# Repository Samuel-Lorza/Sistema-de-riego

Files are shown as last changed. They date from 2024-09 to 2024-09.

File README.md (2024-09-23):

# Sistema-de-riego automatico
Sistema de riego automatico con el uso del ESP32

## Integrantes:

Samuel Lorza-Miguel Pardo-Juan Crespo- Diego García

## Descripción

El presente proyecto, es un sistema de riego automático realizado con un microprocesador de referencia ESP32, la utilidad del sistema radica en la asistencia al usuario para regar plantas en momentos de ausencia, tales como un viaje, una reunión, o que el dueño este ocupado y no pueda cuidar de sus plantas. Con base en lo anterior, el sistema es totalmente programable en cuanto a la temperatura y la humedad que el usuario necesite, dependiendo de las necesidades de la planta. Se ha de mencionar que el usuario debe proveer de agua al sistema, por ejemplo, poniendo un tanque plástico con agua, además, el sistema hará un ruido con el objetivo de recordar al usuario de llenar el tanque (fuente de agua) cuando este tiene un bajo nivel de agua.

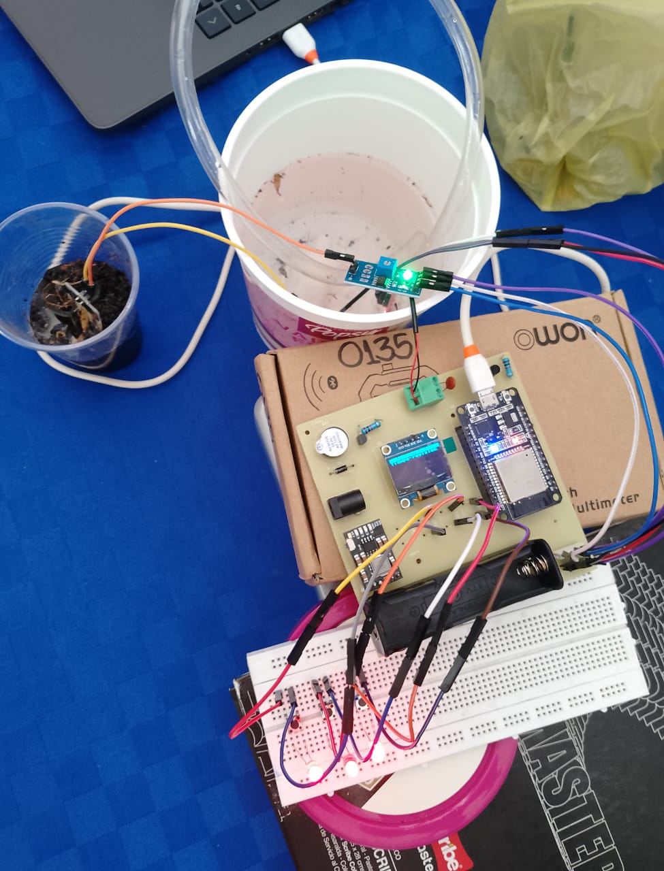
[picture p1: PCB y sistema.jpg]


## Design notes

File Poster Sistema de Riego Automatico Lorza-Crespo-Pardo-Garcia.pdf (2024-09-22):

## Introducción

## Objetivos

El objetivo principal del proyecto es brindar una herramienta sencilla, fácil de implementar y accesible la cual facilite el cuidado de las plantas en el hogar, teniendo en cuenta que no tenga el tiempo necesario para el cuidado de su planta, pero aun así desee tener una en casa pues, aparte de brindar un toque estético, las plantas colaboran en la calidad del aire y esto es aún más significante en las ciudades grandes como Bogotá.

## Impactos

## Placa de Circuito Impreso

## Diagrama de Flujo

# Sistema De Riego Automático

Taller De Ingeniería Electrónica
Johnny German Cubides Castro

Juan Pablo Crespo Gutiérrez jcrespog@unal.edu.co

Miguel Ángel Pardo Castro
mpardoc@unal.edu.co

Samuel Martin Lorza Monroy slorza@unal.edu.co

Diego Garcia Romero
diegarciaro@unal.edu.co
- Reducción de la
huella de carbono.

Nuestro proyecto es un Sistema de Riego Automático realizado con un microprocesador de referencia ESP32 y sensores como, el sensor de nivel del agua y el sensor de humedad y temperatura. La utilidad del sistema radica en la asistencia al usuario para regar plantas en momentos de ausencia y no pueda cuidar de estas. El sistema es totalmente programable en cuanto a la temperatura y la humedad dependiendo de las necesidades de la planta. Se ha de mencionar que el usuario debe proveer de agua al sistema, además, el sistema hará un ruido con el objetivo de recordar al usuario de llenar el tanque (fuente de agua) cuando este tenga un bajo nivel de agua.

- Prevención de un uso
excesivo del agua.
- Uso constante de
energía eléctrica.
- Aumento en el uso y
desechos electrónicos.
- Costos de producción
y mantenimiento.
- Dependencia en la
tecnología.
- Mayor eficiencia en el
manejo del tiempo.
- Accesibilidad y mejora
en la calidad de vida.

La placa de circuito impreso es una superficie que contiene pistas que interconectan los componentes de un aparato
electronico, con el fin de establecer el recorrido de la corriente electrica para el funcionamiento adecuado de un dispositivo.

## Diagrama Tecnologico

El diagrama de flujo es una herramienta que describe
el funcionamiento del
sistema, en cuanto a la
interaccion del usuario y el dispositvo. En el siguiente codigo QR se puede
observar el diagrama de
flujo del proyecto con mas detalle

Figura 1
Huella PCB

Figura 3
Diagrama tecnológico

Figura 2
Esquematico PCB

Figura 4
Diagrama de flujo

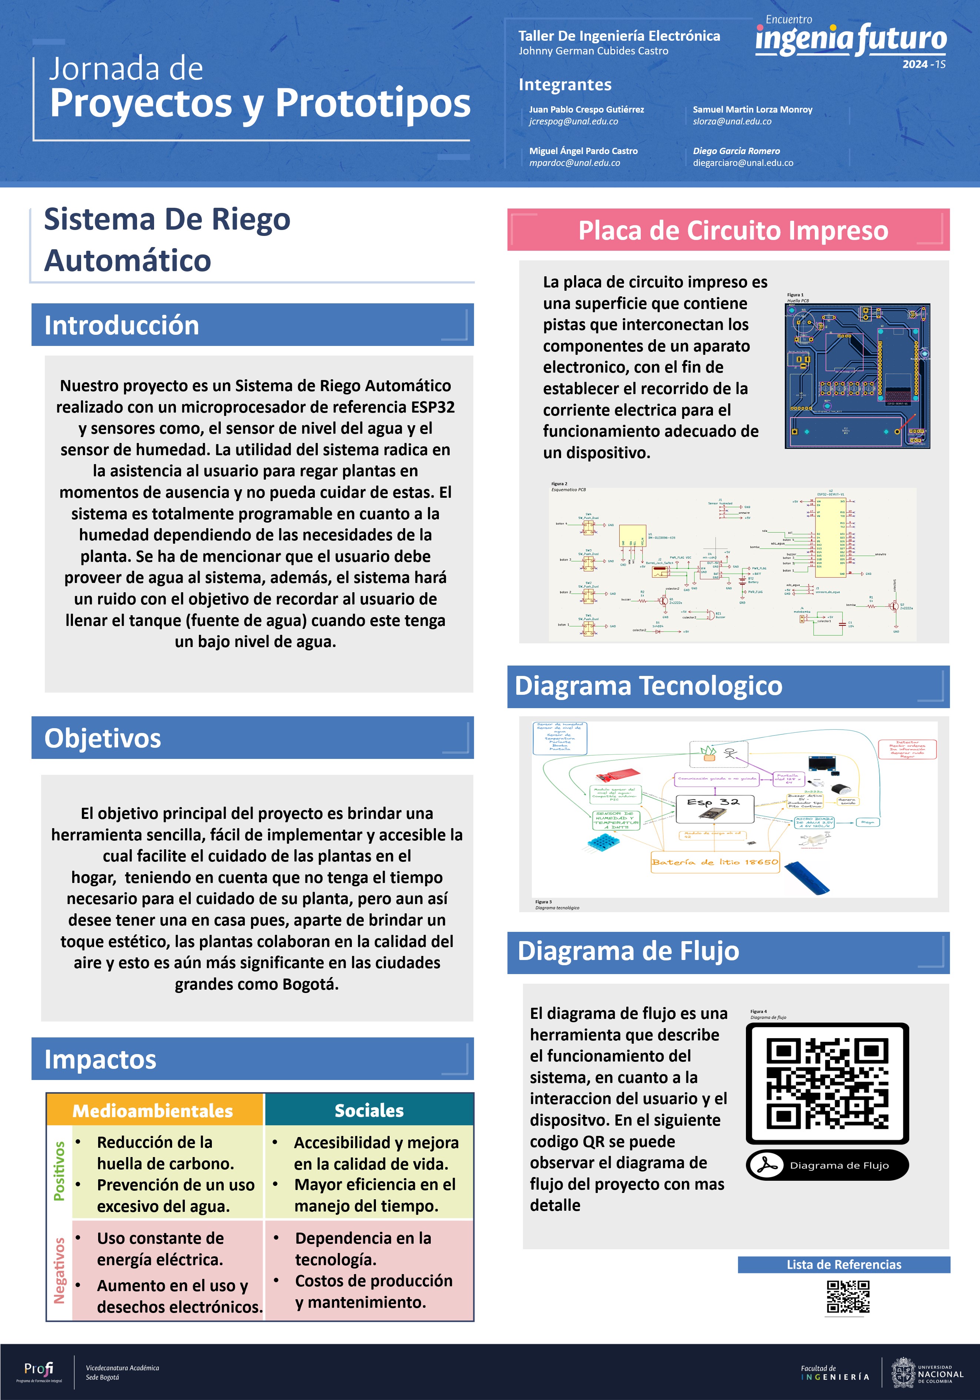
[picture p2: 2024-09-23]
Poster Sistema de Riego Automatico.jpg

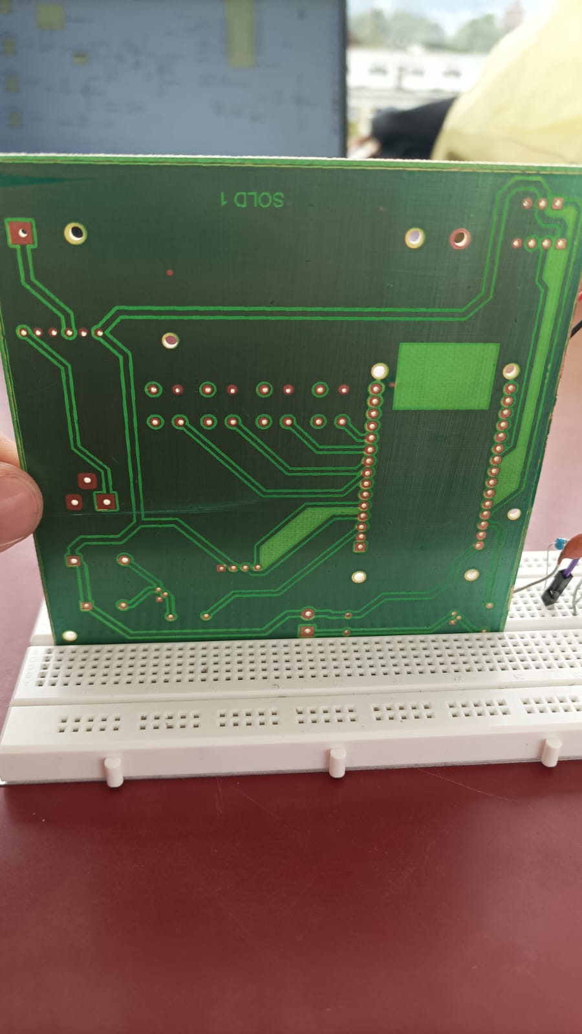
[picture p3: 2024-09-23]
Imagenes Evidencia/PCB impresa vista posterior.jpg

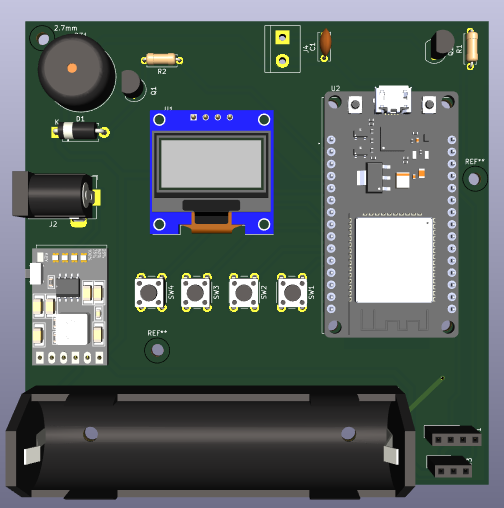
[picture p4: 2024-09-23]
Diseño de PCB/KiCad/Diseño 3D de la PCB (parte frontal).png

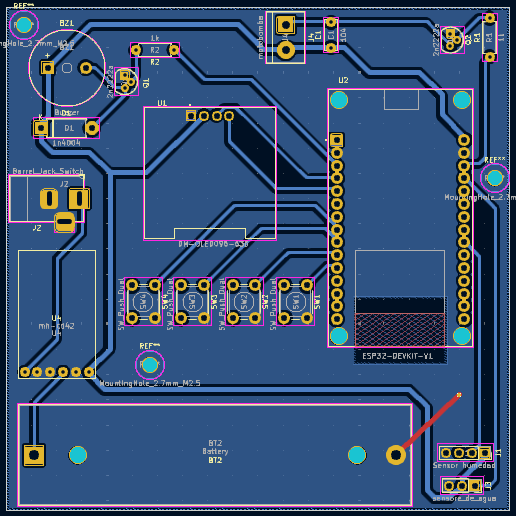
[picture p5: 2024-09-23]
Diseño de PCB/KiCad/Diseño de PCB layout (imagen del ruteo).png

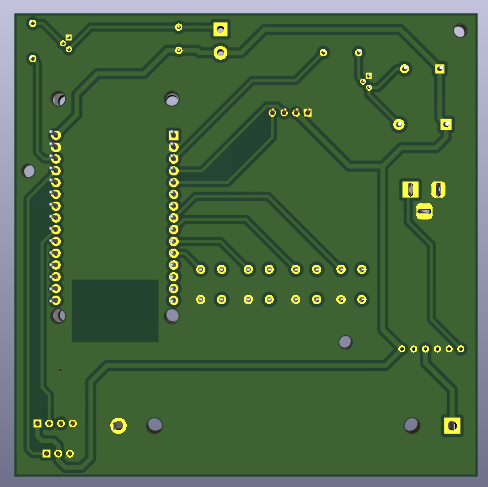
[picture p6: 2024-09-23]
Diseño de PCB/KiCad/Diseño 3D de la PCB (parte trasera).png

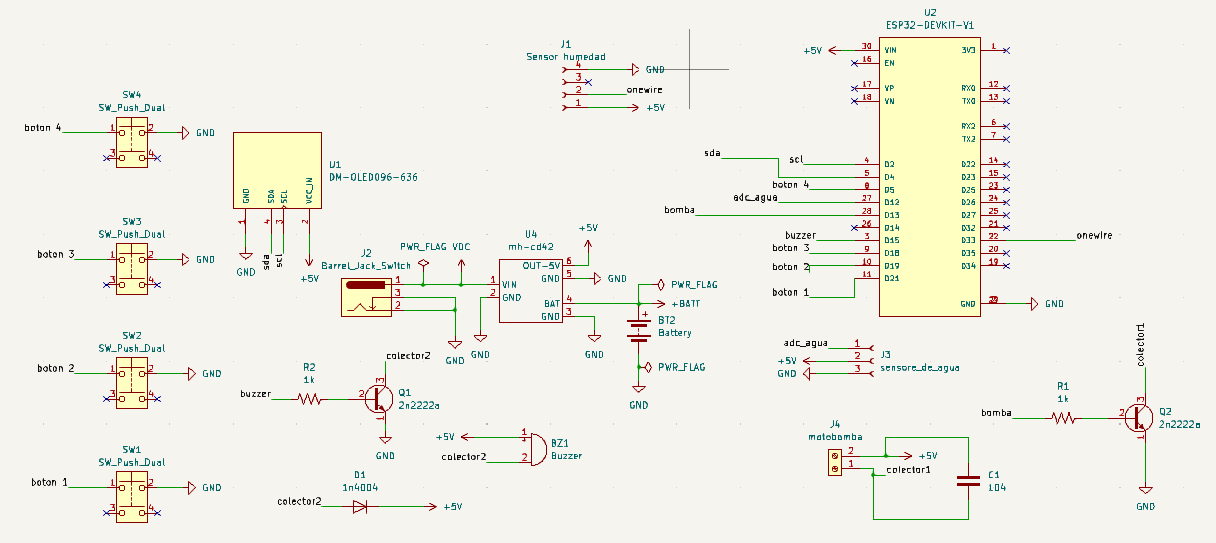
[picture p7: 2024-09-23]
Diseño de PCB/KiCad/Esquematico PCB.png

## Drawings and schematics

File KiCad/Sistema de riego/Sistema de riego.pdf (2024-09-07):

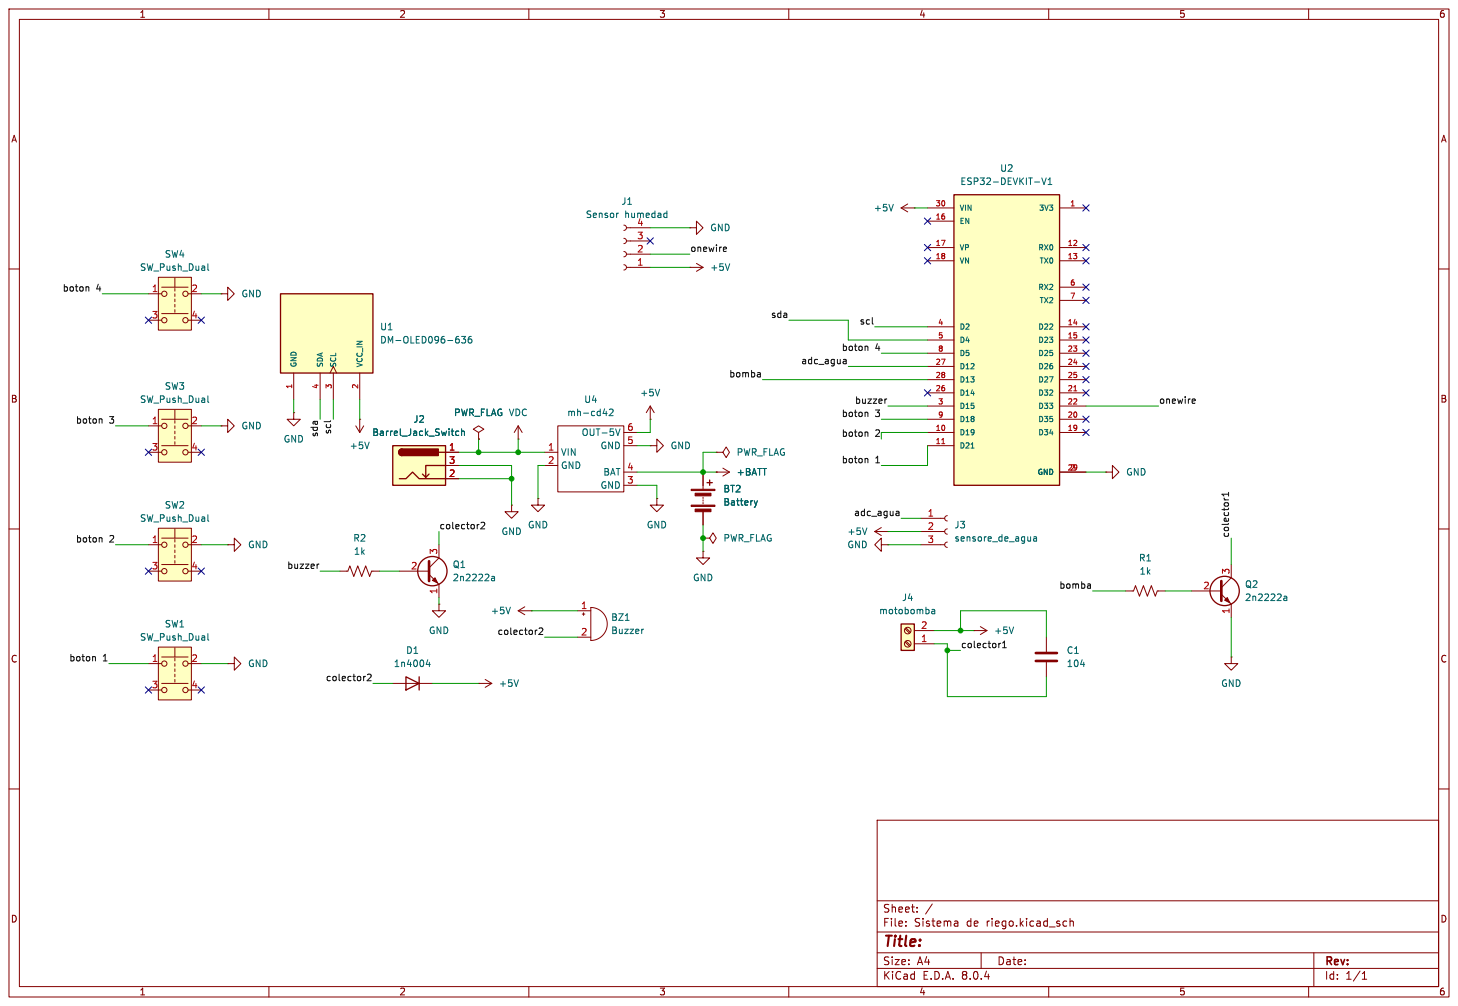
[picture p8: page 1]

Id: 1/1 Title: File: Sistema de riego.kicad_sch Sheet: /

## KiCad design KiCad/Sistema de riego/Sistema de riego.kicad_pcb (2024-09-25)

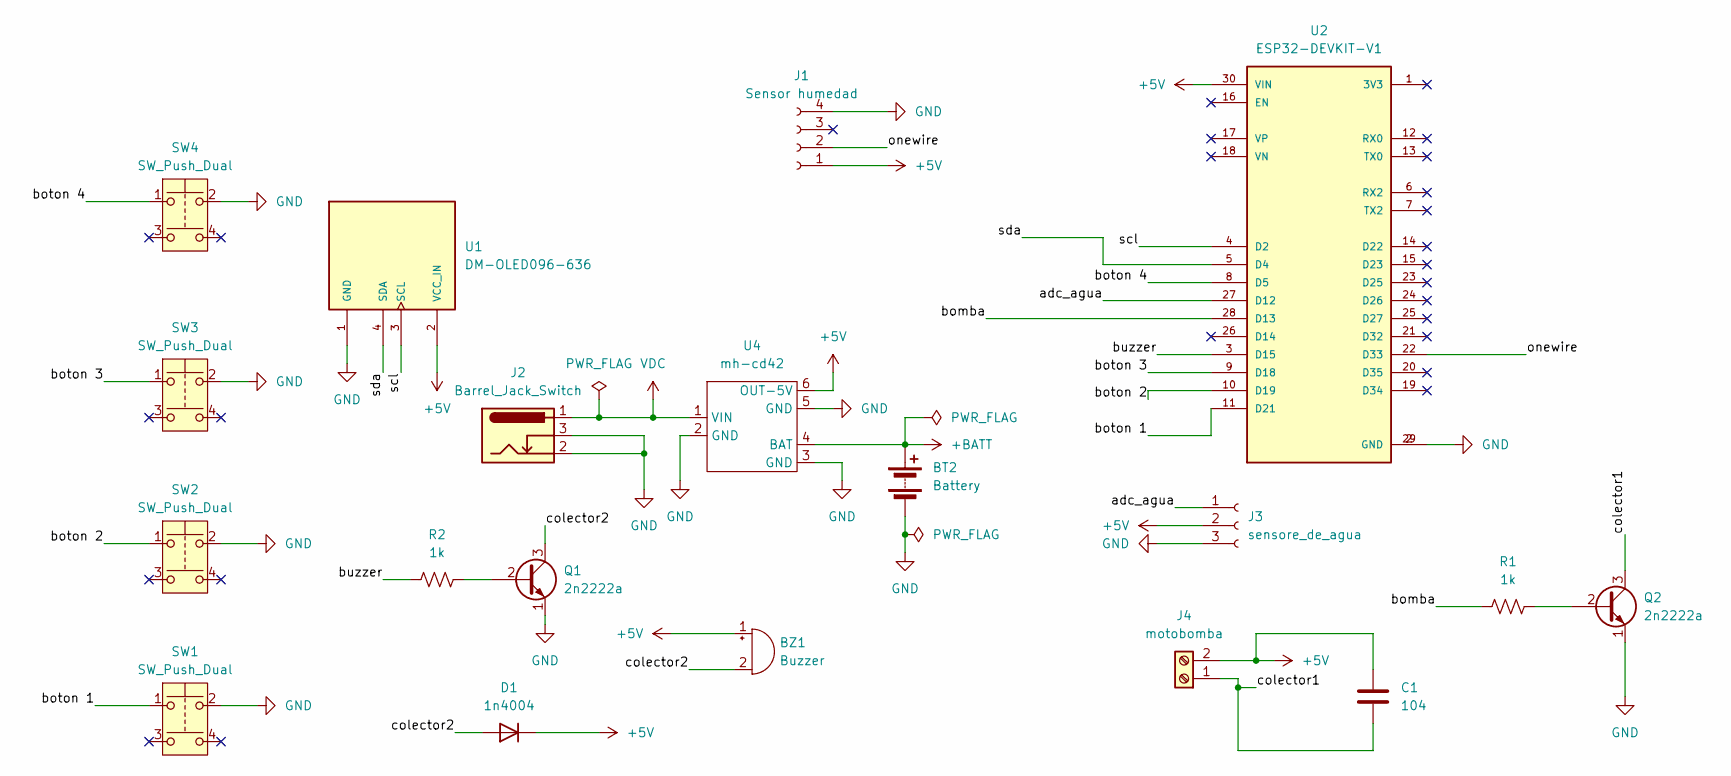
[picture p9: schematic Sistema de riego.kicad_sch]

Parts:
BT2: Battery; BatteryHolder_MPD_BH-18650-PC2
BZ1: Buzzer; Buzzer_15x7.5RM7.6
C1: 104; C_Disc_D6.0mm_W2.5mm_P5.00mm
D1: 1n4004; D_DO-15_P10.16mm_Horizontal
J1: Sensor humedad; PinSocket_1x04_P2.54mm_Vertical
J2: Barrel_Jack_Switch; BarrelJack_Horizontal
J3: sensore_de_agua; PinSocket_1x03_P2.54mm_Vertical
J4: motobomba; TerminalBlock_bornier-2_P5.08mm
Q1, Q2: 2n2222a; TO-92
R1, R2: 1k; R_Axial_DIN0207_L6.3mm_D2.5mm_P7.62mm_Horizontal
SW1, SW2, SW3, SW4: SW_Push_Dual; SW_PUSH_6mm_H4.3mm
U1: DM-OLED096-636; MODULE_DM-OLED096-636; PARTREV 2018-09-10
U2: ESP32-DEVKIT-V1; MODULE_ESP32_DEVKIT_V1; PARTREV N/A
U4: mh-cd42

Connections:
+5V: BZ1.1 (+), C1.1, D1.1 (K), J1.1, J3.2, J4.2, U1.2 (VCC_IN), U2.30 (VIN), U4.6 (OUT-5V)
+BATT: BT2.1 (+), U4.4 (BAT)
/adc_agua: J3.1, U2.27 (D12)
/bomba: R1.1, U2.28 (D13)
/boton 1: SW1.1, U2.11 (D21)
/boton 2: SW2.1, U2.10 (D19)
/boton 3: SW3.1, U2.9 (D18)
/boton 4: SW4.1, U2.8 (D5)
/buzzer: R2.1, U2.3 (D15)
/colector1: C1.2, J4.1, Q2.3 (C)
/colector2: BZ1.2 (-), D1.2 (A), Q1.3 (C)
/onewire: J1.2, U2.22 (D33)
/scl: U1.3 (SCL), U2.4 (D2)
/sda: U1.4 (SDA), U2.5 (D4)
GND: BT2.2 (-), J1.4, J2.2, J2.3, J3.3, Q1.1 (E), Q2.1 (E), SW1.2, SW2.2, SW3.2, SW4.2, U1.1 (GND), U2.2 (GND), U2.29 (GND), U4.2 (GND), U4.3 (GND), U4.5 (GND)
unnamed: Q1.2 (B), R2.2
unnamed: Q2.2 (B), R1.2
VDC: J2.1, U4.1 (VIN)

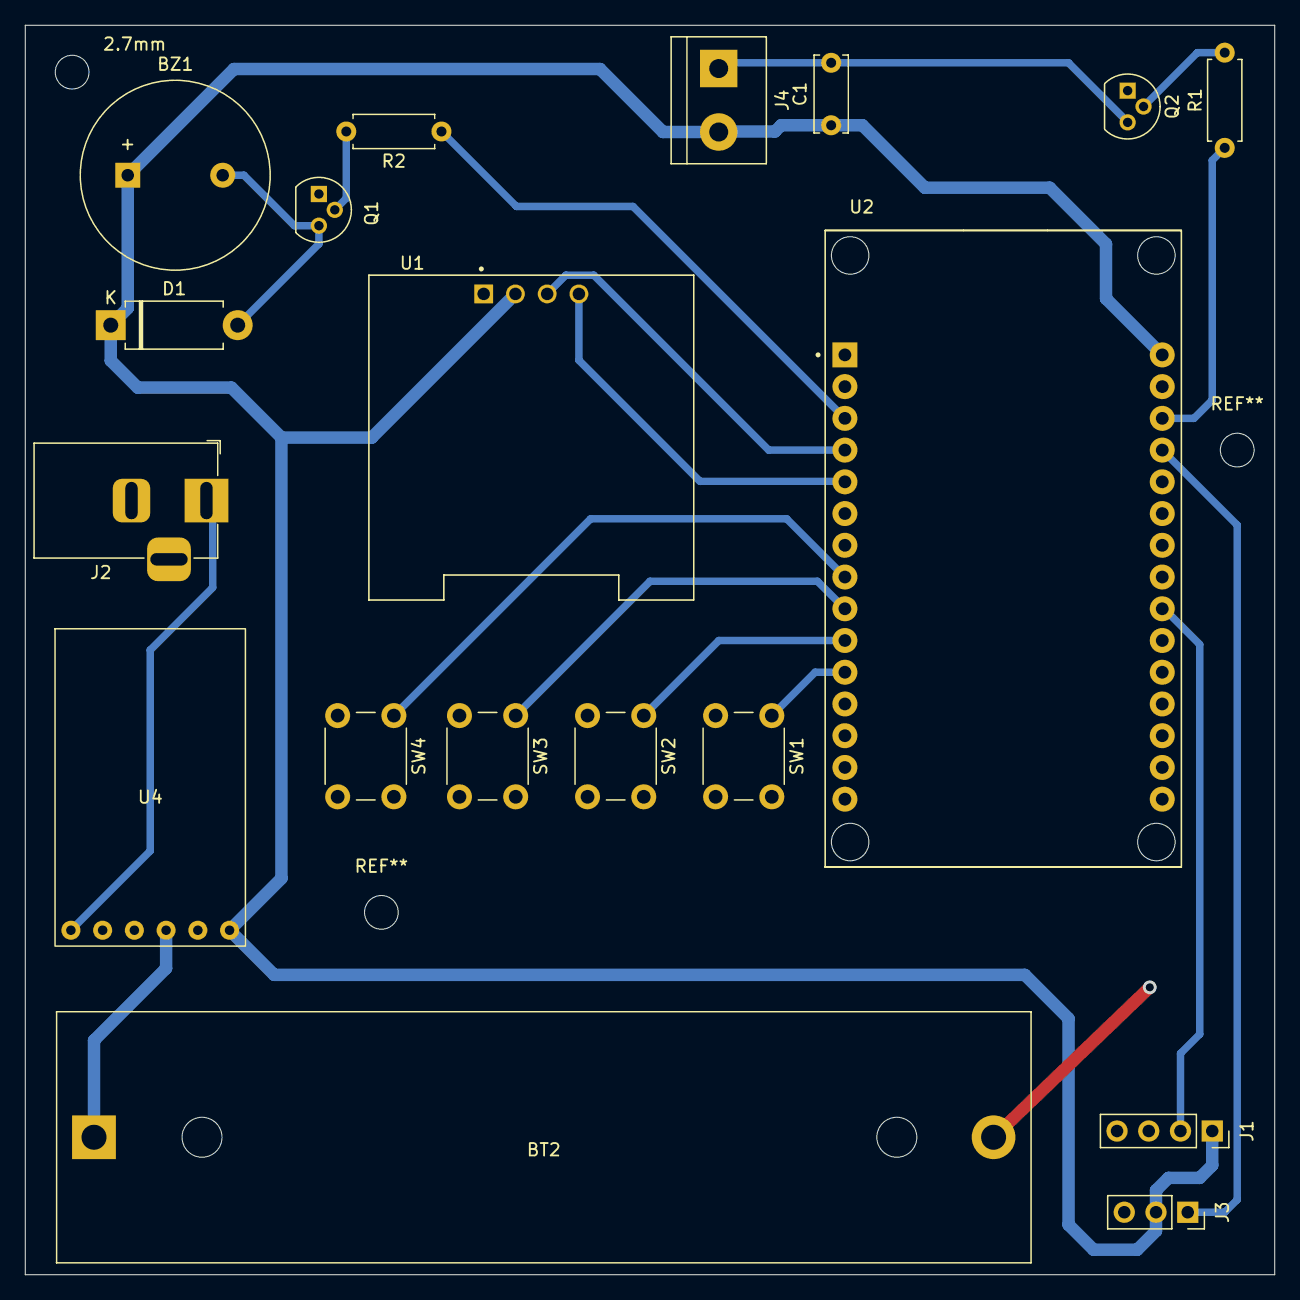
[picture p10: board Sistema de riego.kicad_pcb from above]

Board: 2 copper layers, 100.0 x 100.0 mm, 20 parts (0 on the bottom side), 18 nets.

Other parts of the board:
2.7mm: MountingHole_2.7mm_M2.5

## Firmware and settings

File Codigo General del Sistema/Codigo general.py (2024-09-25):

#Primer codigo de prueba del sistema
#Distintos imports de bibliotecas para las funciones del sistema
from machine import Pin, PWM, ADC, RTC, I2C, deepsleep
import time, ssd1306
from menuoled import MENU_OPTIONS, NAVIGATE_MENU
import esp32

def show_main_menu():
    print("Menú principal")
    main_menu.draw()

def humedad_option():
    print("Opción 1 seleccionada")
    humedad_opcion.draw()


def tiempo_option():
    print("Opción 2 seleccionada")
    tiempo_revision.draw()
    
def humedad25_elegida():
    global humedad
    humedad=(25)
    main_menu.draw()
    return humedad
def humedad50_elegida():
    global humedad
    humedad= 50
    main_menu.draw()
    return humedad
def humedad75_elegida():
    global humedad
    humedad= 75
    main_menu.draw()
    return humedad
def humedad100_elegida():
    global humedad
    humedad= 90
    main_menu.draw()
    return humedad
def tiempo_elegida():
    global tiempo
    tiempo= 1
    main_menu.draw()
    return tiempo
def tiempo1_elegida():
    global tiempo
    tiempo= 60
    main_menu.draw()
    return tiempo
def tiempo2_elegida():
    global tiempo
    tiempo= 120
    main_menu.draw()
    return tiempo

def agua (adcA,buzzer):
    while True:
        bomba=PWM(Pin(13))
        bomba.deinit()
        time.sleep(2)
        Nagua= adcA.read_u16()
        Vbuzz=int(Nagua/1000)
        if Vbuzz < 48:
            buzzer.init()
            buzzer.freq(1000)
            buzzer.duty_u16(50000)
        else:
            buzzer.deinit()
            break
            
def PorcentajeHumedad (adcH,bomba,H_usuario):
    contador=int(0)
    while True:
        Nhumedad= adcH.read_u16()
        Nhumedad_real=(65535-Nhumedad)
        Nhumedadp=int(Nhumedad_real/655.35)
        if (Nhumedadp < H_usuario-5):
            bomba.init()
            bomba.freq(500)
            bomba.duty_u16(40000)
        else:
            bomba.deinit()
            contador= contador + 1
            if (contador==3):
                break
        time.sleep(0.5)

#Zona donde se establecen las variables
        
    #Pin del sensor de humedad
adcH= ADC(Pin(33,Pin.IN))
adcH.atten(ADC.ATTN_11DB)
    #Pin de la bomba de agua
PinBomba=Pin(13)
bomba=PWM(PinBomba)
bomba.deinit()
    #Pin del nivel de agua
adcAgua= ADC(Pin(12,Pin.IN))
adcAgua.atten(ADC.ATTN_11DB)
    #Asignación del buzzer
PinBuzzer=Pin(15)
buzzer=PWM(PinBuzzer)
buzzer.deinit()
    #Asignacion del Real Time Clock
rtc = RTC()
mem = rtc.memory()
    #Botones
        # Configura botones de navegación
abajo = Pin(19, Pin.OUT, Pin.PULL_DOWN)
arriba = Pin(21, Pin.OUT, Pin.PULL_DOWN)
selector = Pin(18, Pin.OUT, Pin.PULL_DOWN)
abajo.on()
arriba.on()
selector.on()
humedad,tiempo=-1,-1



#Creacion de la pantalla OLED, sus menus, opciones etc.
Entrada = I2C(0, scl=Pin(2, Pin.PULL_UP), sda=Pin(4, Pin.PULL_UP))
oled_width = 128
oled_height = 64
oled = ssd1306.SSD1306_I2C(oled_width, oled_height, Entrada)

# Crear un menú principal
main_menu = MENU_OPTIONS(oled)

# Agregar elementos a main_menu
main_menu.add_option("Porcentaje de humedad", humedad_option)
main_menu.add_option("Tiempo de revision", tiempo_option)
#main_menu.add_option("Reinicio", Reinicio)


# Crea menú de la humedad
humedad_opcion = MENU_OPTIONS(oled)

# Agregar elementos al menu de la humedad
humedad_opcion.add_option("Menu principal", show_main_menu)
humedad_opcion.add_option("25%", humedad25_elegida)
humedad_opcion.add_option("50%", humedad50_elegida)
humedad_opcion.add_option("75%", humedad75_elegida)
humedad_opcion.add_option("90%", humedad100_elegida)

# Crear menú del tiempo entre revisiones
tiempo_revision = MENU_OPTIONS(oled)

# Agregar elementos al menú del tiempo entre revisiones
tiempo_revision.add_option("Menu principal", show_main_menu)
tiempo_revision.add_option("Cada 30 min", tiempo_elegida)
tiempo_revision.add_option("1 hora", tiempo1_elegida)
tiempo_revision.add_option("2 horas", tiempo2_elegida)

menu_list = [main_menu,
             humedad_opcion,
             tiempo_revision,
             ]
#Parametro para moverse en el menu
menu = NAVIGATE_MENU(menu_list)

# Dibujar el menú
main_menu.draw()

#Configuracion de las variables para hacer funcionar los botones
print(humedad, tiempo,(humedad>0) and (tiempo>0),(humedad>0), (tiempo>0))    
while True:
        if arriba.value()==0:
            print("Arriba")
            menu.navigate("up")
            time.sleep(0.5)

        if abajo.value()==0:
            print("Abajo")
            menu.navigate("down")
            time.sleep(0.5)

        if selector.value()==0:
            print("Seleccionar")
            menu.select()
            selector.value(1)
            time.sleep(0.5)
            
        if mem:
            # Convertir los bytes a cadena y luego separarlos
            datos = mem.decode().split(',')
            humedad = int(datos[0])  # Primer valor es el contador
            tiempo = int(datos[1])         # Segundo valor es el estado
        if ((int(humedad)>0) and (int(tiempo>0))):
            # Guardar las variables en la memoria RTC como una cadena combinada
            datos_a_guardar = f"{humedad},{tiempo}".encode()
            rtc.memory(datos_a_guardar)
            #Despues de la configuración del sistema, este ciclo hara que todo el tiempo se revisen los parametros        
            agua(adcAgua,buzzer)
            print("salio de la revision X")
            PorcentajeHumedad (adcH,bomba,humedad)
            print("salio de la revision")
            adcH= ADC(Pin(33, Pin.IN, value=0, hold=True))
            adcAgua= ADC(Pin(12,Pin.IN,value=0, hold=True))
            PinBuzzer=Pin(15, Pin.OUT, value=0, hold=True)
            PinBomba=Pin(13, Pin.OUT, value=0, hold=True)
            print("Entrando al deepsleep")
            deepsleep(10000)#tiempo*60000)
    
    
    
    

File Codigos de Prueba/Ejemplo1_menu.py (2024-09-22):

#Ejemplo de menu 1
from machine import Pin, I2C
import ssd1306
from menuoled import MENU_OPTIONS, NAVIGATE_MENU
import time

def eleccion(decenash,unidadesh):
    for x in decenash:
        if x == True:
            decena= int(x)
        else:
            pass
    for x in unidadesh:
        if x == True:
            unidad= int(x)
        else:
            pass
    return decena*10+unidad    
def show_main_menu():
    print("Menú principal")
    main_menu.draw()


def porcentaje_humedad():
    print("Opción 1 seleccionada")
    secondary_menu.draw()
    
def unidades():
    print("Opción 1 seleccionada")
    unidadesh.draw()
    
    
   
def tiempo_revision():
    print("Opción 1 seleccionada")
    secondary_menu.draw()
    
def reinicio():
    print("Opción 1 seleccionada")
    secondary_menu.draw()


def simple_text():
    print("Opción 2 seleccionada")

    simple_text_menu.draw()
    oled.text("Esta es la opcion", 0, 16)
    oled.text("de texto simple", 0, 24)
    oled.show()


def show_icon():
    print("Opción 3 seleccionada")

    show_icon_menu.draw()
    oled.blit(show_icon_menu.openIcon('config'), 20, 16)
    oled.show()


def option_1_1():
    print("Opción 1_1 seleccionada")
    option_1_1_menu.draw()
    oled.text("NADA", 30, 18)
    oled.show()


# Crear un OLED
Entrada = I2C(0, scl=Pin(2, Pin.PULL_UP), sda=Pin(4, Pin.PULL_UP))

oled_width = 128
oled_height = 64
oled = ssd1306.SSD1306_I2C(oled_width, oled_height, Entrada)

# Crear un menú principal
main_menu = MENU_OPTIONS(oled)

# Agregar elementos a main_menu
main_menu.add_option("Porcentaje de humedad", porcentaje_humedad)
main_menu.add_option("Tiempo de revision", tiempo_revision)
main_menu.add_option("Reinicio", reinicio)


# Crea menú de la opción 1
porcentaje_humedad = MENU_OPTIONS(oled)

# Agregar elementos a menu_option_1
porcentaje_humedad.add_option("Selecciona porcentaje de humedad",simple_text)

decenash = MENU_OPTIONS(oled)

decenash.add_option(0, unidades)
decenash.add_option(1, unidades)
decenash.add_option(2, unidades)
decenash.add_option(3, unidades)
decenash.add_option(4, unidades)
decenash.add_option(5, unidades)
decenash.add_option(6, unidades)
decenash.add_option(7, unidades)
decenash.add_option(8, unidades)
decenash.add_option(9, unidades)

unidadesh = MENU_OPTIONS(oled)

unidadesh.add_option(0, show_main_menu)
unidadesh.add_option(1, show_main_menu)
unidadesh.add_option(2, show_main_menu)
unidadesh.add_option(3, show_main_menu)
unidadesh.add_option(4, show_main_menu)
unidadesh.add_option(5, show_main_menu)
unidadesh.add_option(6, show_main_menu)
unidadesh.add_option(7, show_main_menu)
unidadesh.add_option(8, show_main_menu)
unidadesh.add_option(9, show_main_menu)

print(eleccion(decenas,unidades))


# Crea menú de la opción texto simple
 
tiempo_revision.add_option("Selecciona el tiempo que habra entre cada revisión",show_())

tiempo_opcion = MENU_OPTIONS(oled)

tiempo_opcion.add_option(0)
tiempo_opcion.add_option(1)
tiempo_opcion.add_option(2)
tiempo_opcion.add_option(3)
tiempo_opcion.add_option(4)
tiempo_opcion.add_option(5)
tiempo_opcion.add_option(6)
tiempo_opcion.add_option(7)
tiempo_opcion.add_option(8)
tiempo_opcion.add_option(9)

while True:       
    for x in tiempo_opcion:
        if x == True:
            tiempo_r=str(x)
            tiempo_r=+(tiempo_r)
        else:
            pass
        
tiempo_r=int(tiempo_r)    
    
# Agregar elementos a texto simple
tiempo_revision.add_option("Menu principal", show_main_menu)


menu_list = [main_menu,
             decenash,
             unidadesh,
             show_icon_menu,
             option_1_1_menu]

menu = NAVIGATE_MENU(menu_list)

# Configura botones de navegación

abajo = Pin(19, Pin.OUT, Pin.PULL_DOWN)
arriba = Pin(21, Pin.OUT, Pin.PULL_DOWN)
selector = Pin(18, Pin.OUT, Pin.PULL_DOWN)
abajo.on()
arriba.on()
selector.on()


# Dibujar el menú
main_menu.draw()

while True:
    if arriba.value()==0:
        print("Arriba")
        menu.navigate("up")
        time.sleep(0.5)

    if abajo.value()==0:
        print("Abajo")
        menu.navigate("down")
        time.sleep(0.5)

    if selector.value()==0:
        print("Seleccionar")
        menu.select()
        time.sleep(0.5)
    print(arriba.value(),abajo.value(),selector.value())

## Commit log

2024-08-30 Create Diagrama de caja Negra.png
2024-08-31 Esquemático PCB
    Añadir imagen del esquemático de la PCB del proyecto.
2024-09-07 Esquematico PCB
2024-09-22 codigos de prueba y librerias
    Se subieron los códigos de prueba y librerías utilizadas
2024-09-23 Diseño de PCB KiCad
    Se subieron las imágenes de la PCB
2024-09-23 PCb pines soldados
2024-09-23 Adicion de imagen
